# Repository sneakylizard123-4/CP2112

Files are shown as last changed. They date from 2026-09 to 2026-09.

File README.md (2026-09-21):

# CP2112 USB-to-SMBus Bridge Board

A small board based on the CP2112
USB to SMBus/I2C

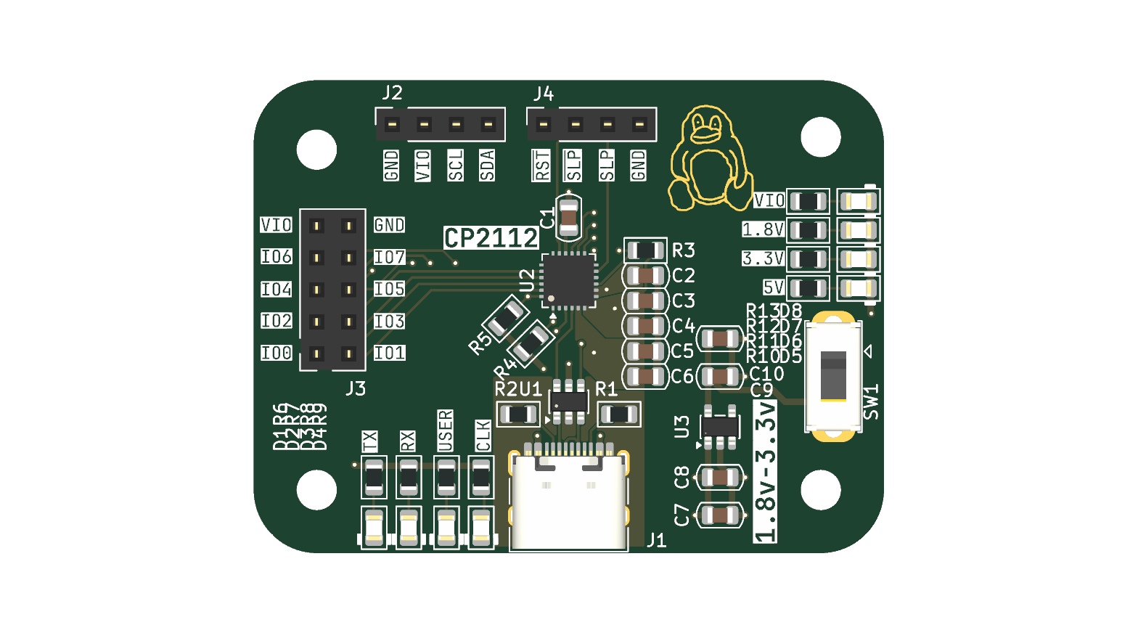
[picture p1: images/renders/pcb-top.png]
PCB render, top
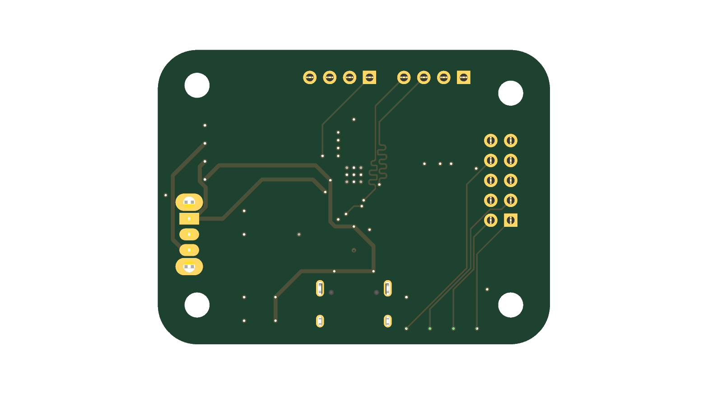
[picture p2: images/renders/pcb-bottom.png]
PCB render, bottom
 

## Custom Features

- CP2112 HID USB-to-SMBus/I2C - no driver install necessary
- USB-C with ESD protection
- On-board 1.8V LDO
- 8x status LEDs
- Breakout headers for I2C/SMBus and GPIO
- Slide switch for VIO selection (3.3v/1.8v)
- 4-layer PCB, 50 x 37.5 mm, 4x M3 mounting holes

## How It Works

USB -> CP2112 -> I2C

| Block | Part | Role |
|---|---|---|
| Bridge | CP2112 | HID USB-to-UART/I2C bridge, crystal-less |
| USB | USB_C_Receptacle_USB2.0_16P (HRO TYPE-C-31-M-12) | Host connection |
| Protection | USBLC6-2SC6 | ESD clamp on D+/D- |
| Power | TLV75718PDBV | 1.8V LDO, powers VIO rail |
| I/O | 2x5 + 1x4 pin headers | UART / SMBus / GPIO access |

### Power Tree

```mermaid
flowchart LR
    VBUS["USB-C VBUS +5V"] --> P5["+5V"]
    P5 --> U2["CP2112 VDD"]
    U2 --> R33["+3.3V internal reg"]
    P5 --> U3["TLV75718PDBV LDO"]
    U3 --> R18["+1.8V"]
    R33 --> SW["SW1 VIO select"]
    R18 --> SW
    SW --> VIO["VIO rail: CP2112, LEDs, pull-ups, headers"]
```

## PCB Design

- 4-layer, 50.00 x 37.50 mm, 1.6 mm, 6 copper zones
- USB kept close to the CP2112, D+/D- routed short on the top layer
- Decoupling caps placed at the CP2112 and LDO pins
- All passives 0805 for easy hand assembly

PCB 3D / layout image

## Firmware

No firmware needed!!

## Usage

- Connect USB
- Connect I2C/SMBus device

Power comes from the USB-C port

## BOM (Bill of Materials)

| Qty | Designator | Value | Package | Part / Link |
|-----|---|---|---|---|
| 1 | C1 | 4.7 uF | 0805 | [C1779](https://www.lcsc.com/product-detail/C1779.html) |
| 4 | C10, C4, C6, C8 | 10 uF | 0805 | [C15850](https://www.lcsc.com/product-detail/C15850.html) |
| 1 | C2 | 1 uF | 0805 | [C28323](https://www.lcsc.com/product-detail/C28323.html) |
| 4 | C3, C5, C7, C9 | 100 nF | 0805 | [C49678](https://www.lcsc.com/product-detail/C49678.html) |
| 8 | D1-D8 | LED | 0805 | [C84256](https://www.lcsc.com/product-detail/C84256.html) |
| 1 | J1 | USB-C receptacle USB 2.0 | HRO TYPE-C-31-M-12 | [C165948](https://www.lcsc.com/product-detail/C165948.html) |
| 2 | J2, J4 | Pin socket 1x04 | 2.54 mm | [C2718488](https://www.lcsc.com/product-detail/C2718488.html) |
| 1 | J3 | Pin socket 2x05 | 2.54 mm | [C30419](https://jlcpcb.com/partdetail/31176-2_54mm25p/C30419) |
| 2 | R1, R2 | 5.1k | 0805 | [C27834](https://www.lcsc.com/product-detail/C27834.html) |
| 8 | R6-R13 | 1k | 0805 | [C17513](https://www.lcsc.com/product-detail/C17513.html) |
| 1 | R3 | 10k | 0805 | [C17414](https://www.lcsc.com/product-detail/C17414.html) |
| 2 | R4, R5 | 4.7k | 0805 | [C17673](https://www.lcsc.com/product-detail/C17673.html) |
| 1 | SW1 | Slide switch SPDT | CK OS102011MS2Q | [C221829](https://www.lcsc.com/product-detail/C221829.html) |
| 1 | U1 | USBLC6-2SC6 | SOT-23-6 | [C7519](https://www.lcsc.com/product-detail/C7519.html) |
| 1 | U2 | CP2112 | QFN-24 4x4 mm | [C2678020](https://www.lcsc.com/product-detail/C2678020.html) |
| 1 | U3 | TLV75718PDBV | SOT-23-5 | [C507270](https://www.lcsc.com/product-detail/C507270.html) |

Full BOM with prices and MOQ at [BOM.csv](BOM.csv)

## Production

standard JLCPCB 4-layer PCB

## Repository Structure

```
├── kicad/            # PCB source files
│   └── production/   # Gerbers, BOM + positions csv
├── cad/              # .step export + native CAD source
├── firmware/         # Firmware source code (if any)
├── images/           # renders/ + schematic/ screenshots
└── JOURNAL.md        # Work journal
```

## Known Issues

- Hasn't been built yet

## Credits & Inspiration

- CP2112 Datasheet for reference design

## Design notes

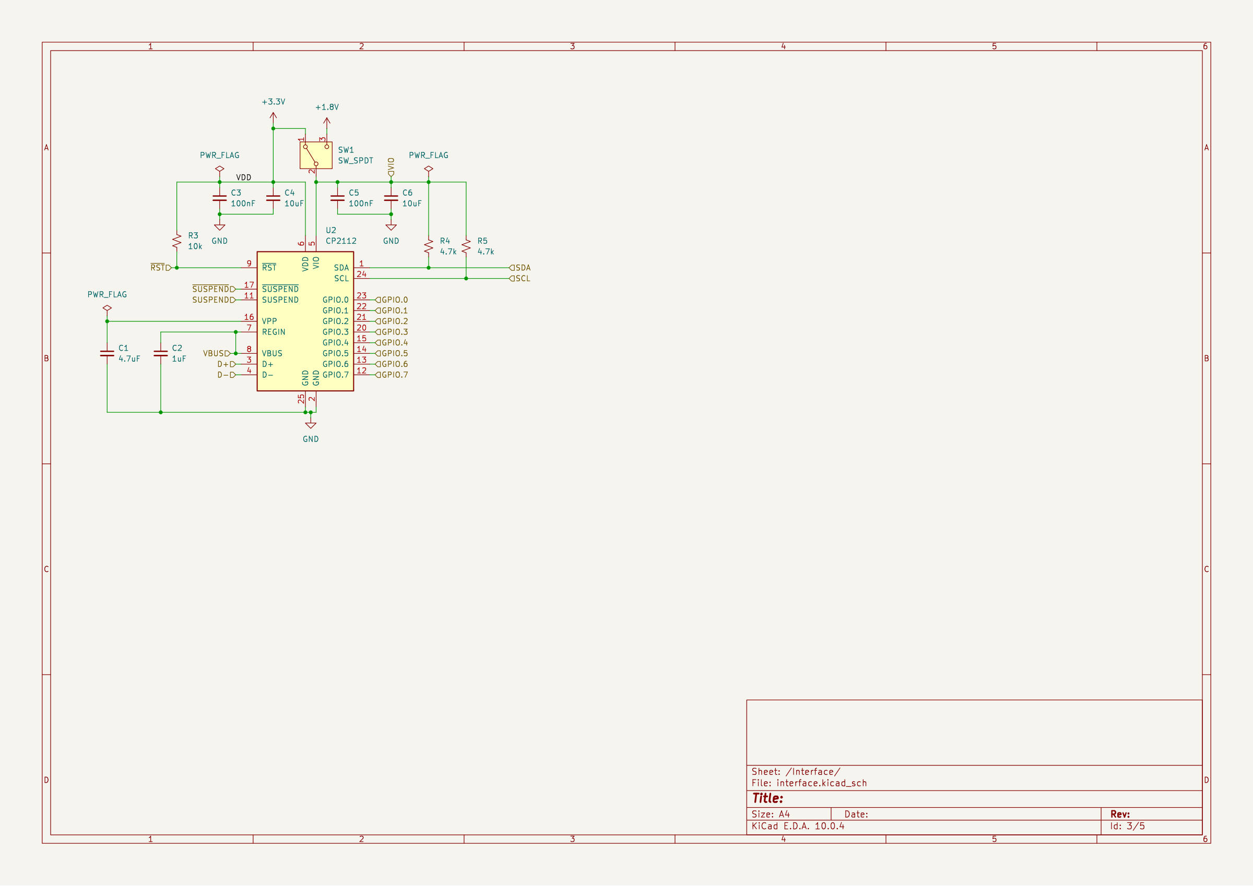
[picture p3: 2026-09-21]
images/schematic/03-interface.png

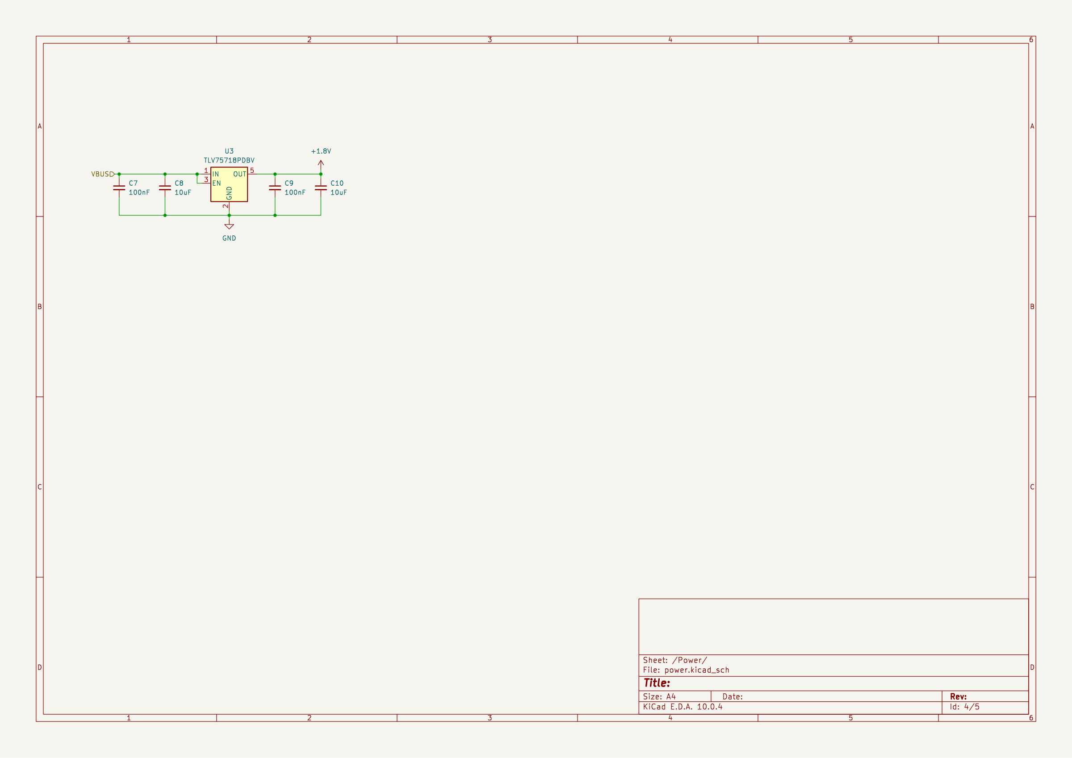
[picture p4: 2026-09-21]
images/schematic/04-power.png

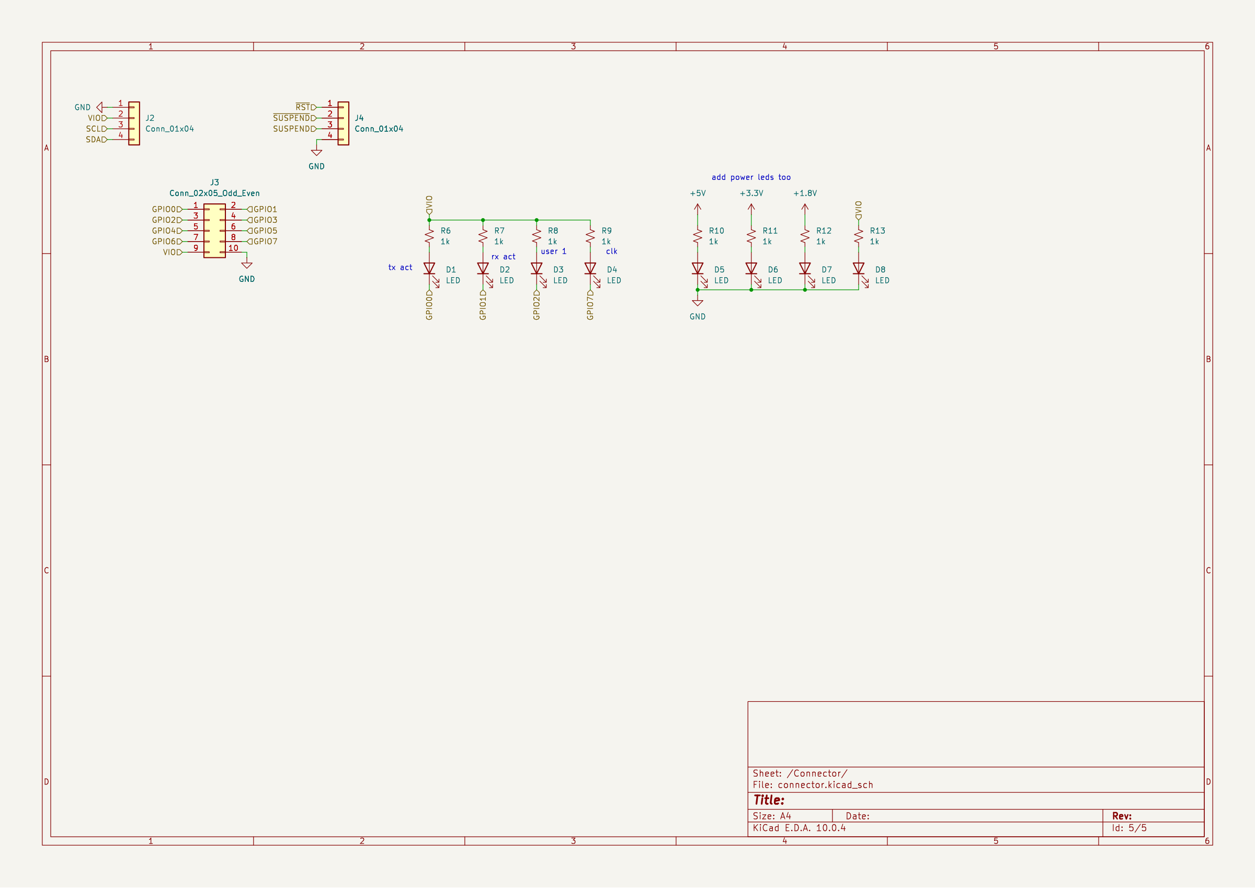
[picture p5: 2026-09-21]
images/schematic/05-connector.png

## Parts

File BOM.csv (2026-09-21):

Designator | Value | Footprint | Qty Needed | MOQ | Qty Ordered | LCSC Part # | Supplier Link | Unit Price @ MOQ (USD) | Line Total (USD)
R1 R2 | 5.1k | 0805 | 2 | 100 | 100 | C27834 | https://www.lcsc.com/product-detail/C27834.html | 0.006 | 0.60
R3 | 10k | 0805 | 1 | 100 | 100 | C17414 | https://www.lcsc.com/product-detail/C17414.html | 0.0039 | 0.39
R4 R5 | 4.7k | 0805 | 2 | 100 | 100 | C17673 | https://www.lcsc.com/product-detail/C17673.html | 0.0051 | 0.51
R6-R13 | 1k | 0805 | 8 | 100 | 100 | C17513 | https://www.lcsc.com/product-detail/C17513.html | 0.0041 | 0.41
C1 | 4.7uF | 0805 | 1 | 20 | 20 | C1779 | https://www.lcsc.com/product-detail/C1779.html | 0.0348 | 0.70
C2 | 1uF | 0805 | 1 | 10 | 10 | C28323 | https://www.lcsc.com/product-detail/C28323.html | 0.0403 | 0.40
C3 C5 C7 C9 | 100nF | 0805 | 4 | 20 | 20 | C49678 | https://www.lcsc.com/product-detail/C49678.html | 0.0195 | 0.39
C4 C6 C8 C10 | 10uF | 0805 | 4 | 20 | 20 | C15850 | https://www.lcsc.com/product-detail/C15850.html | 0.0852 | 1.70
D1-D8 | LED red | 0805 | 8 | 50 | 50 | C84256 | https://www.lcsc.com/product-detail/C84256.html | 0.0135 | 0.68
J1 | USB Type-C | 16P USB2.0 | 1 | 5 | 5 | C165948 | https://www.lcsc.com/product-detail/C165948.html | 0.1879 | 0.94
J2 J4 | Pin socket 1x4 | THT 2.54mm | 2 | 10 | 10 | C2718488 | https://www.lcsc.com/product-detail/C2718488.html | 0.0793 | 0.79
J3 | Pin socket 2x5 | THT 2.54mm | 1 | 5 | 5 | C30419 | https://jlcpcb.com/partdetail/31176-2_54mm25p/C30419 | 0.1182 | 0.59
SW1 | Slide switch SPDT | THT C&K OS102011 | 1 | 1 | 1 | C221829 | https://www.lcsc.com/product-detail/C221829.html | 0.662 | 0.66
U1 | USBLC6-2SC6 | SOT-23-6 | 1 | 5 | 5 | C7519 | https://www.lcsc.com/product-detail/C7519.html | 0.1782 | 0.89
U2 | CP2112-F03-GMR | QFN-24 4x4 | 1 | 1 | 1 | C2678020 | https://www.lcsc.com/product-detail/C2678020.html | 6.2024 | 6.20
U3 | TLV75718PDBVR | SOT-23-5 | 1 | 5 | 5 | C507270 | https://www.lcsc.com/product-detail/C507270.html | 0.3151 | 1.58
TOTAL |  |  |  |  |  |  |  | 17.43

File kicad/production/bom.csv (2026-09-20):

Designator | Footprint | Quantity | Value | LCSC Part #
C1 | 0805 | 1 | 4.7uF
C10, C4, C6, C8 | 0805 | 4 | 10uF
C2 | 0805 | 1 | 1uF
C3, C5, C7, C9 | 0805 | 4 | 100nF
D1, D2, D3, D4, D5, D6, D7, D8 | 0805 | 8 | LED
J1 | USB_C_Receptacle_HRO_TYPE-C-31-M-12 | 1 | USB_C_Receptacle_USB2.0_16P
J2, J4 | PinSocket_1x04_P2.54mm_Vertical | 2 | Conn_01x04
J3 | PinSocket_2x05_P2.54mm_Vertical | 1 | Conn_02x05_Odd_Even
R1, R2 | 0805 | 2 | 5.1k
R10, R11, R12, R13, R6, R7, R8, R9 | 0805 | 8 | 1k
R3 | 0805 | 1 | 10k
R4, R5 | 0805 | 2 | 4.7k
SW1 | SW_Slide_SPDT_Straight_CK_OS102011MS2Q | 1 | SW_SPDT
U1 | SOT-23-6 | 1 | USBLC6-2SC6
U2 | QFN-24-1EP_4x4mm_P0.5mm_EP2.6x2.6mm | 1 | CP2112
U3 | SOT-23-5 | 1 | TLV75718PDBV

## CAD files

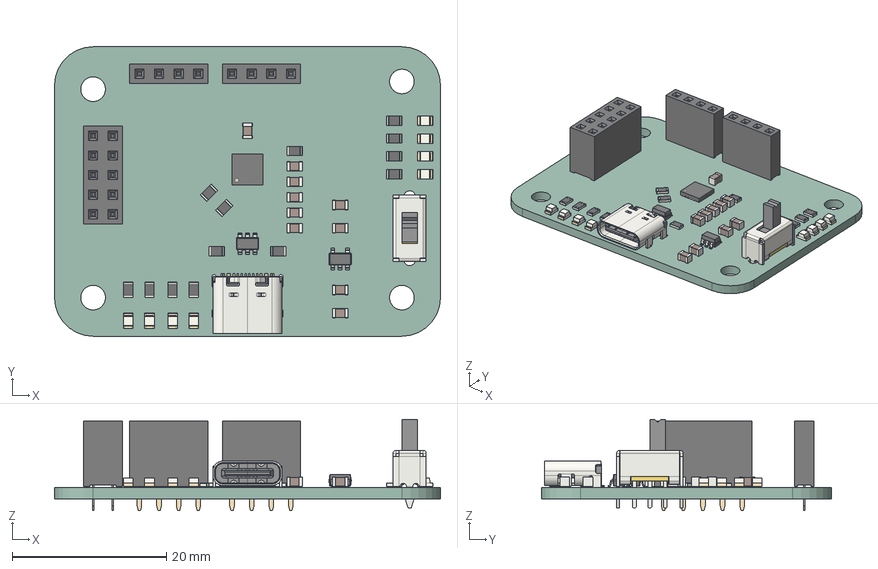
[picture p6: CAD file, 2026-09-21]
cad/CP2112.step
50.0 x 37.5 x 11.8 mm
LED_0805_2012Metric x 8
R_0805_2012Metric x 13
C_0805_2012Metric x 10
PinSocket_2x05_P2.54mm_Vertical
PinSocket_1x04_P2.54mm_Vertical x 2
QFN-24-1EP_4x4mm_Pitch0.5mm
USB_C_Receptacle_16P_TopMnt_Horizontal_GCT_USB4105-xx-A
SOT-23-6
SW_Slide_SPDT_Straight_CK_OS102011MS2Q
SOT-23-5
CP2112_PCB

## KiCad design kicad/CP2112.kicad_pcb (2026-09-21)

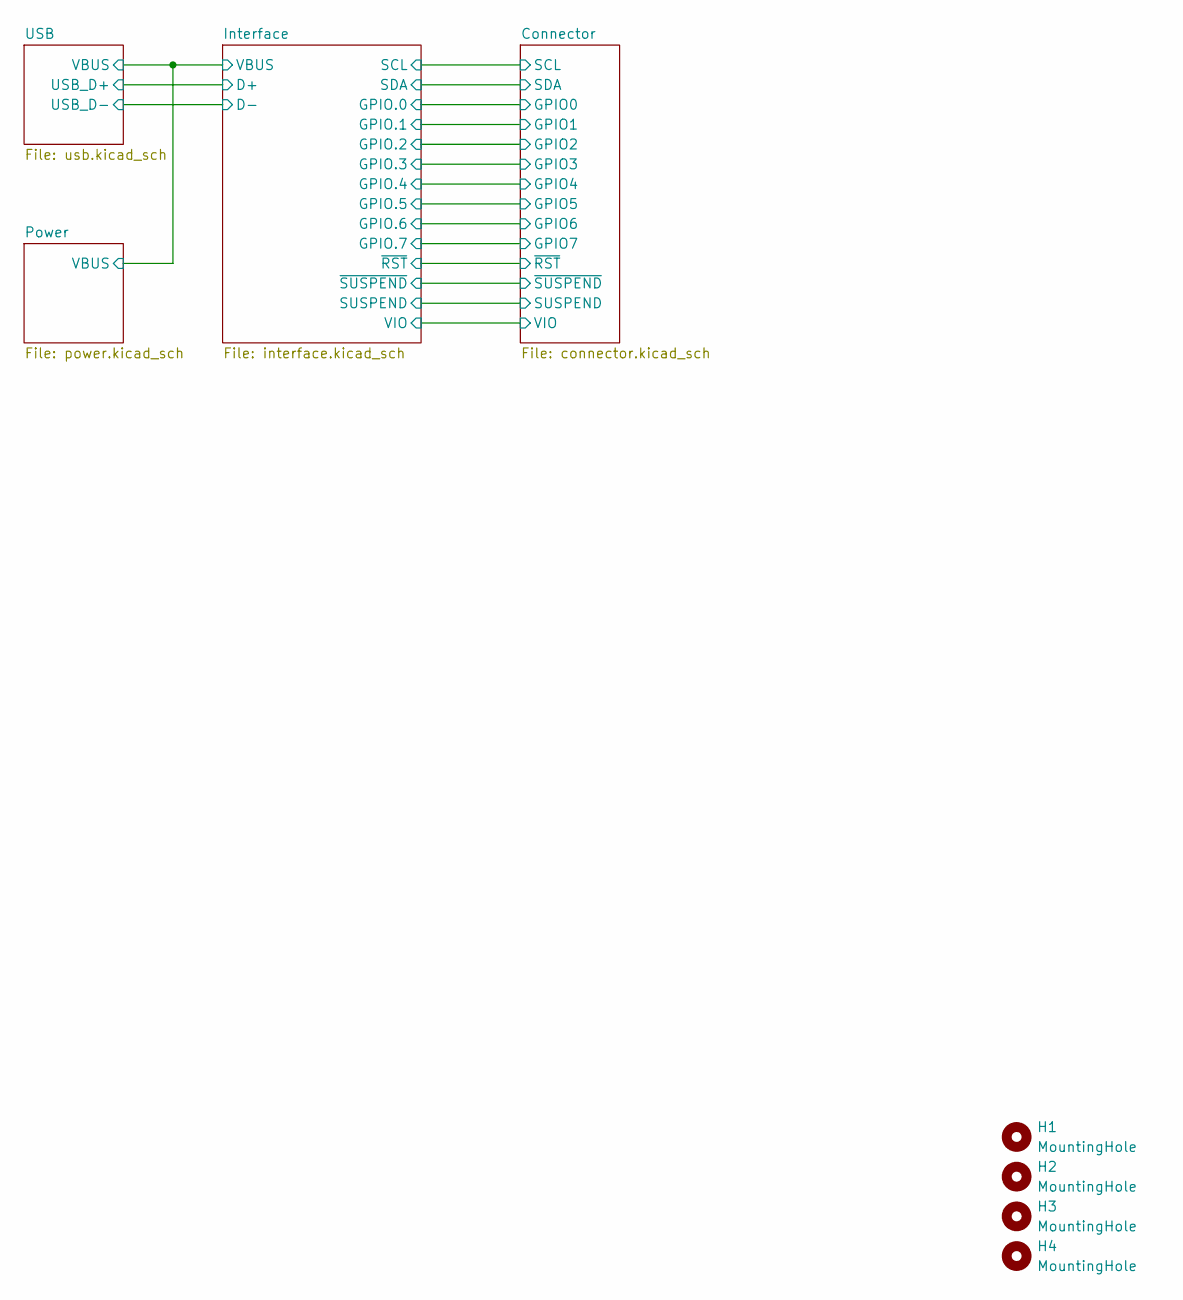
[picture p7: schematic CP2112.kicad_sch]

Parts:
H1, H2, H3, H4: MountingHole; MountingHole_3.2mm_M3

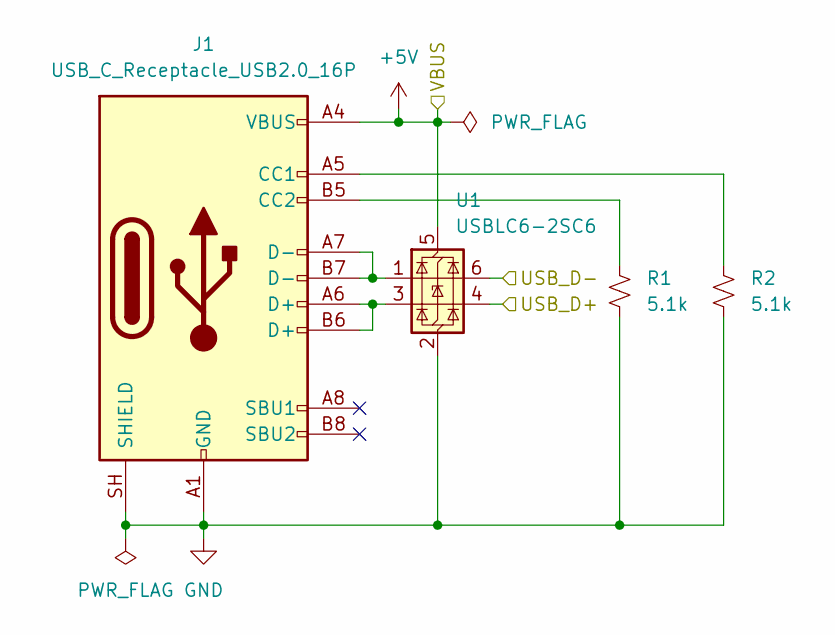
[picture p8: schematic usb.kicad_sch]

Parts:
J1: USB_C_Receptacle_USB2.0_16P; USB_C_Receptacle_HRO_TYPE-C-31-M-12
R1, R2: 5.1k; R_0805_2012Metric
U1: USBLC6-2SC6; SOT-23-6

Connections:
+5V: J1.A4 (VBUS), J1.A9 (VBUS), J1.B4 (VBUS), J1.B9 (VBUS), U1.5 (VBUS); also elsewhere on the board
/Interface/D+: U1.4 (I/O2); also elsewhere on the board
/Interface/D-: U1.6 (I/O1); also elsewhere on the board
GND: J1.A1 (GND), J1.A12 (GND), J1.B1 (GND), J1.B12 (GND), J1.SH (SHIELD), R1.2, R2.2, U1.2 (GND); also elsewhere on the board
unnamed: J1.A5 (CC1), R2.1
unnamed: J1.B5 (CC2), R1.1
unnamed: J1.A6 (D+), J1.B6 (D+), U1.3 (I/O2)
unnamed: J1.A7 (D-), J1.B7 (D-), U1.1 (I/O1)

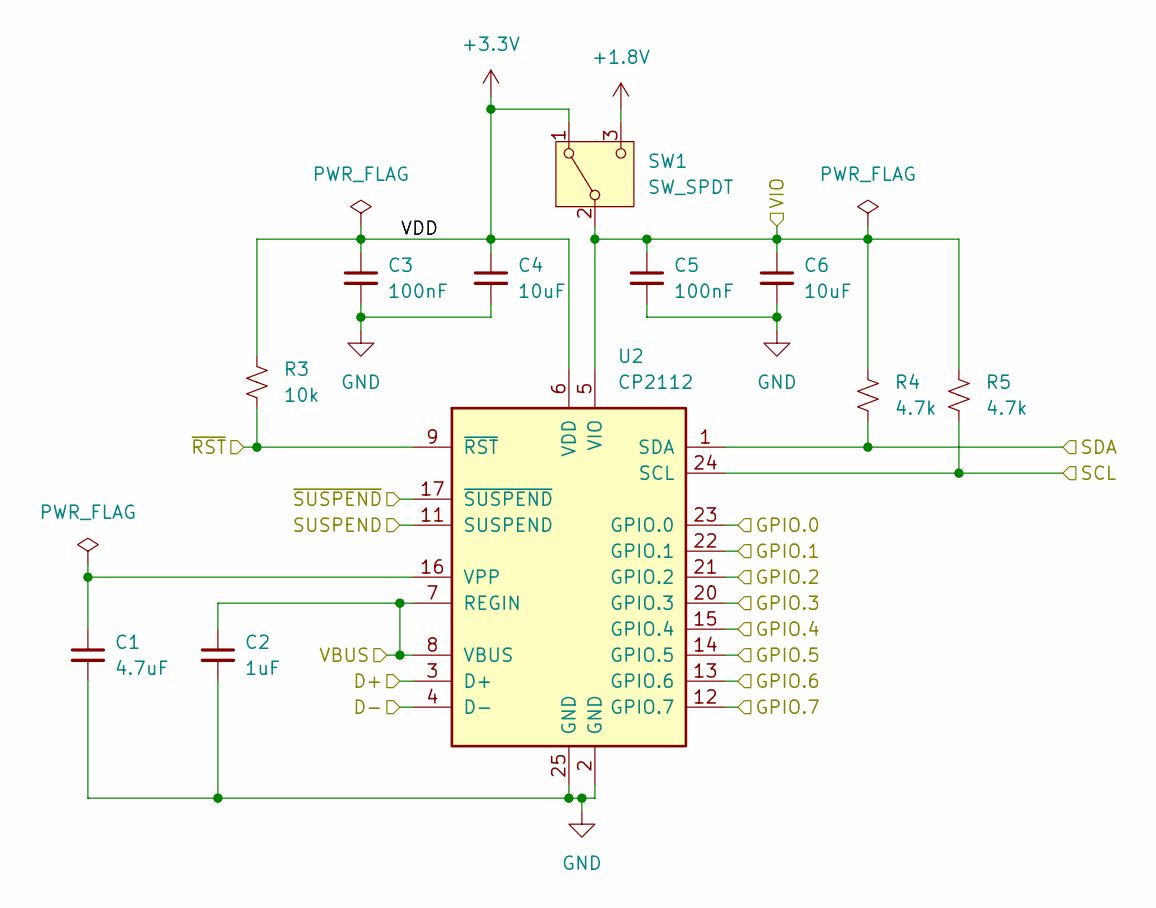
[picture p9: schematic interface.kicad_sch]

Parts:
C1: 4.7uF; C_0805_2012Metric
C2: 1uF; C_0805_2012Metric
C3, C5: 100nF; C_0805_2012Metric
C4, C6: 10uF; C_0805_2012Metric
R3: 10k; R_0805_2012Metric
R4, R5: 4.7k; R_0805_2012Metric
SW1: SW_SPDT; SW_Slide_SPDT_Straight_CK_OS102011MS2Q
U2: CP2112; QFN-24-1EP_4x4mm_P0.5mm_EP2.6x2.6mm

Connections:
+1.8V: SW1.3 (C); also elsewhere on the board
+3.3V: C3.1, C4.1, R3.1, SW1.1 (A), U2.6 (VDD); also elsewhere on the board
+5V: C2.1, U2.7 (REGIN), U2.8 (VBUS); also elsewhere on the board
/Connector/GPIO0: U2.23 (GPIO.0); also elsewhere on the board
/Connector/GPIO1: U2.22 (GPIO.1); also elsewhere on the board
/Connector/GPIO2: U2.21 (GPIO.2); also elsewhere on the board
/Connector/GPIO3: U2.20 (GPIO.3); also elsewhere on the board
/Connector/GPIO4: U2.15 (GPIO.4); also elsewhere on the board
/Connector/GPIO5: U2.14 (GPIO.5); also elsewhere on the board
/Connector/GPIO6: U2.13 (GPIO.6); also elsewhere on the board
/Connector/GPIO7: U2.12 (GPIO.7); also elsewhere on the board
/Connector/SCL: R5.2, U2.24 (SCL); also elsewhere on the board
/Connector/SDA: R4.2, U2.1 (SDA); also elsewhere on the board
/Connector/SUSPEND: U2.11 (SUSPEND); also elsewhere on the board
/Connector/VIO: C5.1, C6.1, R4.1, R5.1, SW1.2 (B), U2.5 (VIO); also elsewhere on the board
/Connector/~RST: R3.2, U2.9 (~RST); also elsewhere on the board
/Connector/~SUSPEND: U2.17 (~SUSPEND); also elsewhere on the board
/Interface/D+: U2.3 (D+); also elsewhere on the board
/Interface/D-: U2.4 (D-); also elsewhere on the board
GND: C1.2, C2.2, C3.2, C4.2, C5.2, C6.2, U2.2 (GND), U2.25 (GND); also elsewhere on the board
unnamed: C1.1, U2.16 (VPP)

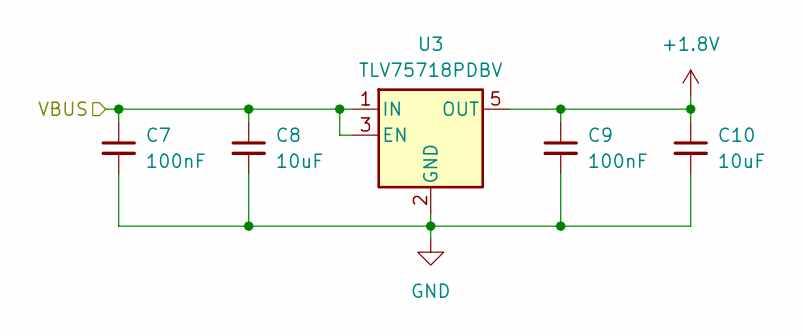
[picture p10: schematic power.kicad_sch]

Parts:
C7, C9: 100nF; C_0805_2012Metric
C8, C10: 10uF; C_0805_2012Metric
U3: TLV75718PDBV; SOT-23-5

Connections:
+1.8V: C9.1, C10.1, U3.5 (OUT); also elsewhere on the board
+5V: C7.1, C8.1, U3.1 (IN), U3.3 (EN); also elsewhere on the board
GND: C7.2, C8.2, C9.2, C10.2, U3.2 (GND); also elsewhere on the board

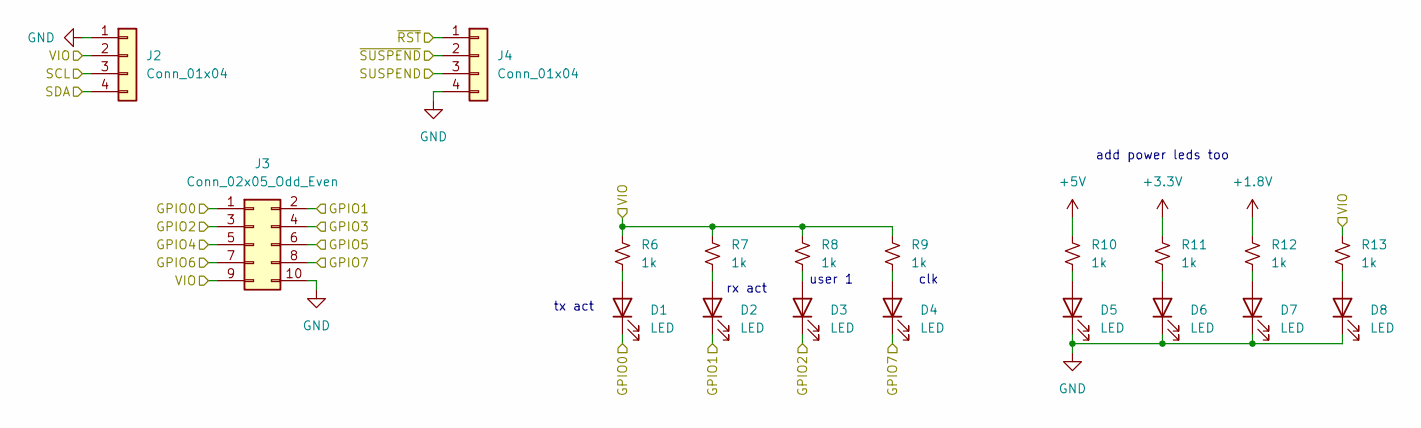
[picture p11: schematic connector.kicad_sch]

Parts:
D1, D2, D3, D4, D5, D6, D7, D8: LED; LED_0805_2012Metric
J2, J4: Conn_01x04; PinSocket_1x04_P2.54mm_Vertical
J3: Conn_02x05_Odd_Even; PinSocket_2x05_P2.54mm_Vertical
R6, R7, R8, R9, R10, R11, R12, R13: 1k; R_0805_2012Metric

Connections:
+1.8V: R12.1; also elsewhere on the board
+3.3V: R11.1; also elsewhere on the board
+5V: R10.1; also elsewhere on the board
/Connector/GPIO0: D1.1 (K), J3.1; also elsewhere on the board
/Connector/GPIO1: D2.1 (K), J3.2; also elsewhere on the board
/Connector/GPIO2: D3.1 (K), J3.3; also elsewhere on the board
/Connector/GPIO3: J3.4; also elsewhere on the board
/Connector/GPIO4: J3.5; also elsewhere on the board
/Connector/GPIO5: J3.6; also elsewhere on the board
/Connector/GPIO6: J3.7; also elsewhere on the board
/Connector/GPIO7: D4.1 (K), J3.8; also elsewhere on the board
/Connector/SCL: J2.3; also elsewhere on the board
/Connector/SDA: J2.4; also elsewhere on the board
/Connector/SUSPEND: J4.3; also elsewhere on the board
/Connector/VIO: J2.2, J3.9, R6.1, R7.1, R8.1, R9.1, R13.1; also elsewhere on the board
/Connector/~RST: J4.1; also elsewhere on the board
/Connector/~SUSPEND: J4.2; also elsewhere on the board
GND: D5.1 (K), D6.1 (K), D7.1 (K), D8.1 (K), J2.1, J3.10, J4.4; also elsewhere on the board
unnamed: D1.2 (A), R6.2
unnamed: D2.2 (A), R7.2
unnamed: D3.2 (A), R8.2
unnamed: D4.2 (A), R9.2
unnamed: D5.2 (A), R10.2
unnamed: D6.2 (A), R11.2
unnamed: D7.2 (A), R12.2
unnamed: D8.2 (A), R13.2

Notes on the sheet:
clk
add power leds too
tx act
rx act
user 1

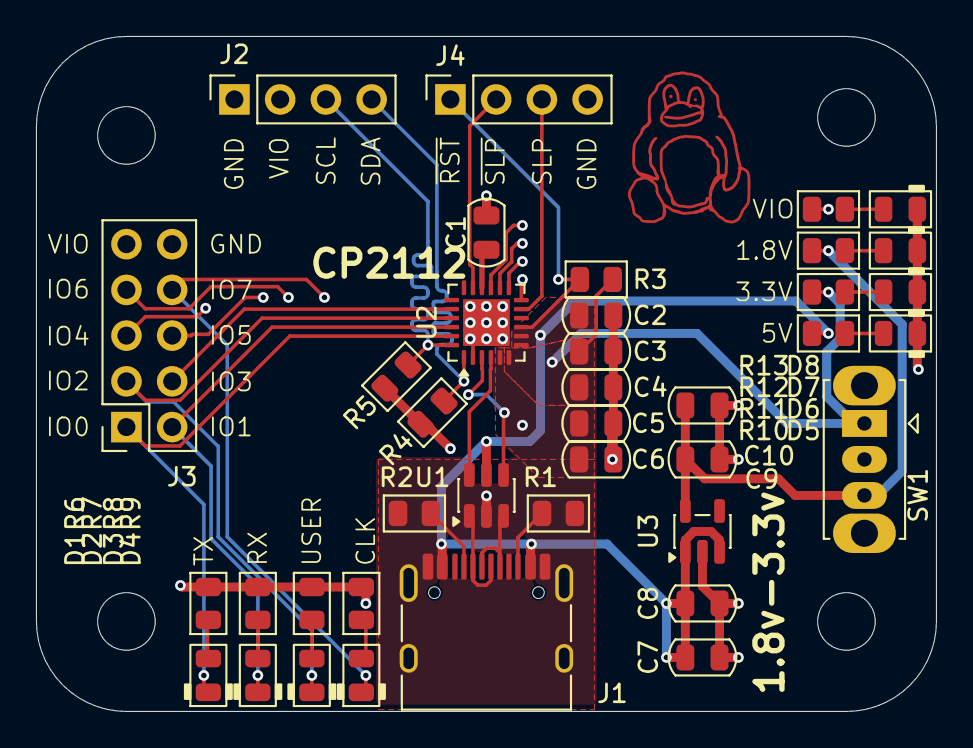
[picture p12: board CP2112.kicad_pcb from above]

Board: 4 copper layers, 50.0 x 37.5 mm, 43 parts (0 on the bottom side), 33 nets.

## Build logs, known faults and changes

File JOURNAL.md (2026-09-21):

---
title: CP2112 USB-to-UART Bridge Board
author: sneakylizard123-4
description: USB-C breakout for the CP2112, with 1.8V
created_at: 2026-09-19
---

# September 19: PCB start

## What I did:

- started with usb-c with cc resistors
- Built the interface sheet around the CP2112
- Added a power sub-sheet for TLV75718PDBV 1.8V LDO
- Added the connector sub-sheet for 2x5 and 1x4 pin headers
- 8x status LEDs with 1k series resistors
- Created the PCB and started placement/routing (4-layer, 50 x 37.5 mm)

## Why:

- 50x37.5 is half of 50x75mm
- also probably cheaper than regular 50x75mm
- 1.8v just in case, so i can use it for 3.3v and 1.8v
- lots of leds for debugging

## Screenshots:

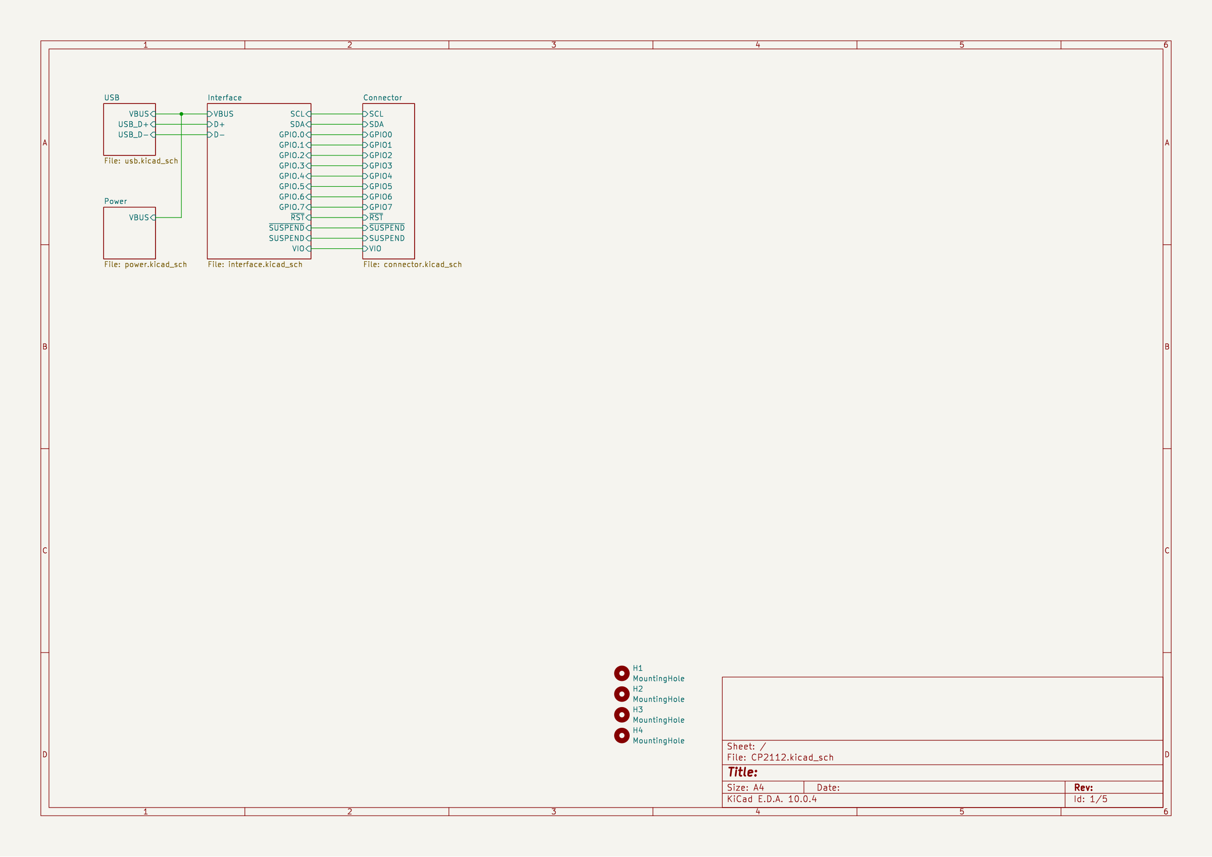
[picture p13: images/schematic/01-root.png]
schematic root sheet

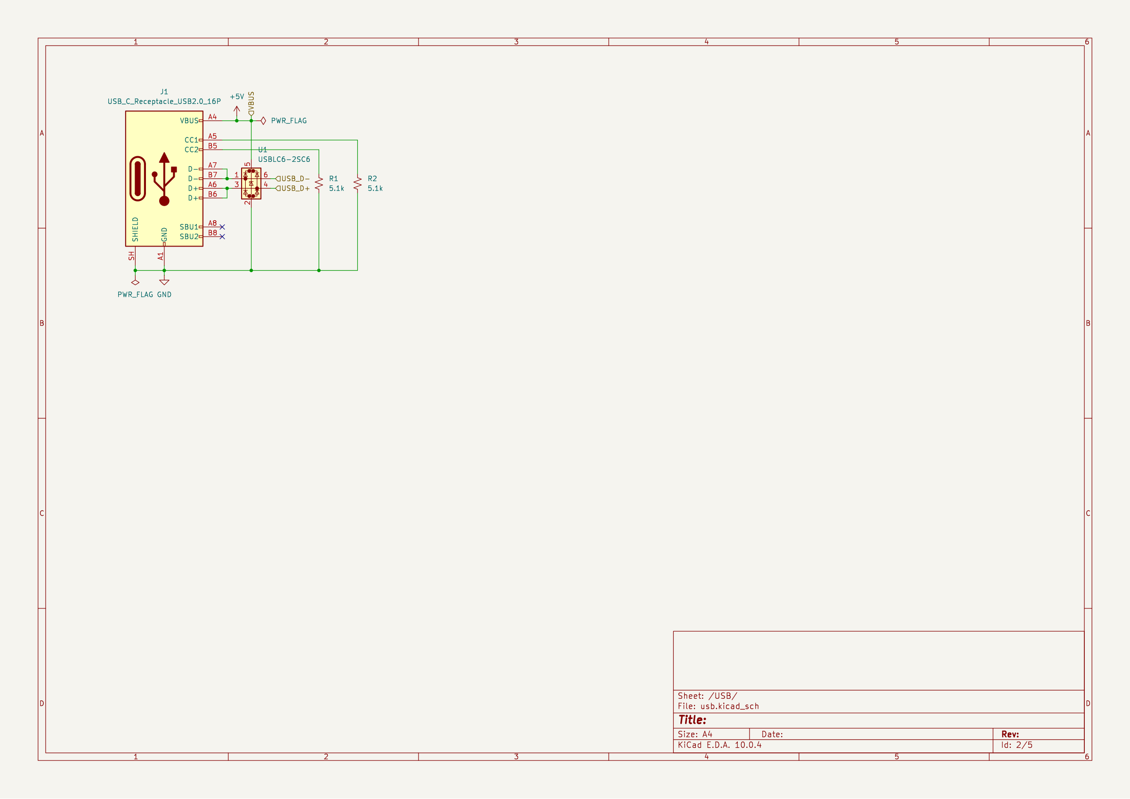
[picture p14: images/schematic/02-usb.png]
USB sub-sheet


**Total time spent: 4 hours**

# September 20: Layout

## What I did:

- continued routing, cleanup before production export
- Generated production outputs
- Generated pcb renders
- generated cad model

## Why:

- hack club forge requirements

## Screenshots:

PCB render, top
PCB render, bottom
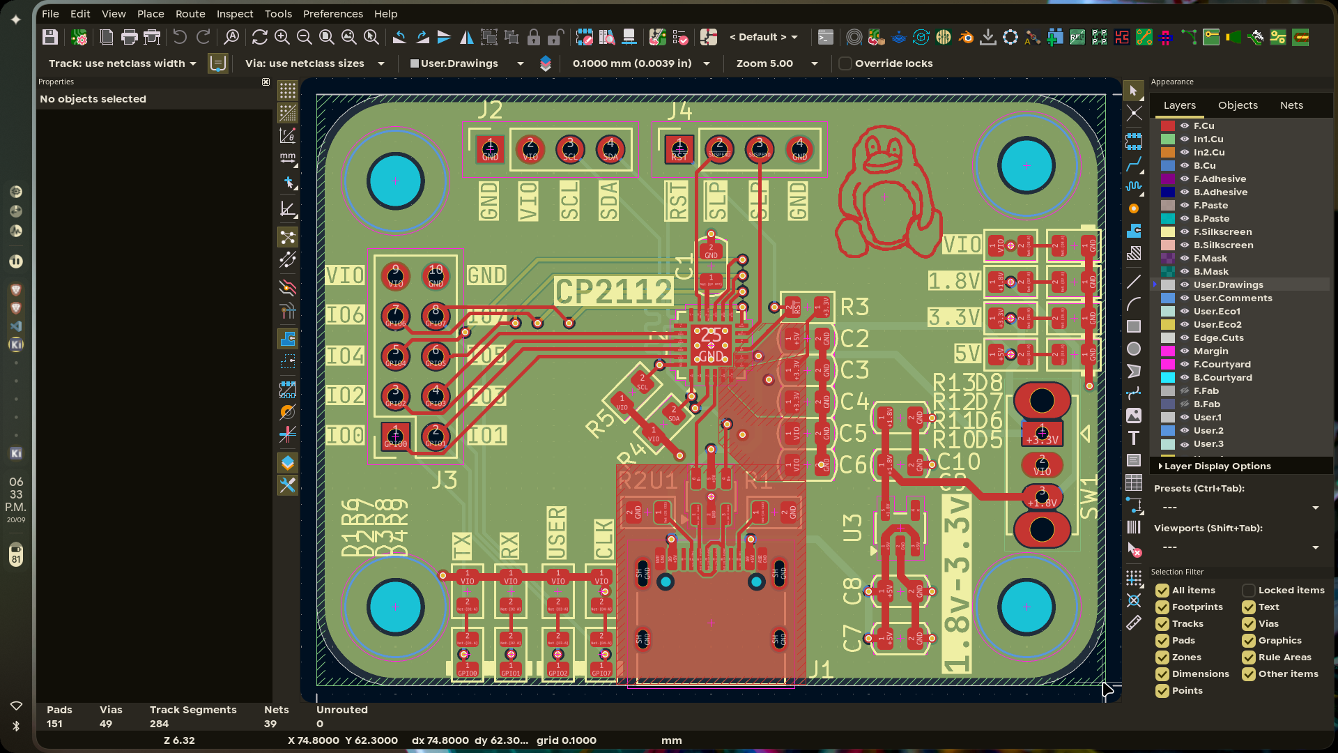
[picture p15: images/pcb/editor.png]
PCB editor


**Total time spent: 4 hours**

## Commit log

2026-09-21 add images
    [CP2112.kicad_pcb, CP2112.step]
2026-09-21 add bom
    [BOM.csv]
